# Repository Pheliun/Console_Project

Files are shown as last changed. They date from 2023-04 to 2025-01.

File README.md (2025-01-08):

This was my final project to get my Cyber Diploma.
It involved creating a basic functional console that when connected to a power supply (using micro usb b), will be able to utilize a microprocessor, with a display, micro sd card socket, and buttons.
For a detailed explanation regarding my project, here is my project book: https://docs.google.com/document/d/1XIzdJ6GN7S2lS_oo8KrGg07EBY5Gj0uBNZ1zpXOEC-Y/edit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

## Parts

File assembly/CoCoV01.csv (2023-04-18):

Comment | Designator | Footprint | LCSC
4.7uF | C1,C2,C4 | Capacitor_SMD:C_0805_2012Metric | C1779
10uF | C3,C5 | Capacitor_SMD:C_1206_3216Metric | C13585
100nF | C6,C7,C8 | Capacitor_SMD:C_0402_1005Metric | C24497
600mA | D1 | Diode_SMD:D_SOD-323 | C191023
MountingHole_Pad | H1,H2,H3,H4 | MountingHole:MountingHole_4.3mm_M4_Pad_Via
SWD CONN | J1 | Connector_PinHeader_1.27mm:PinHeader_2x05_P1.27mm_Vertical_SMD | C2881910
Conn_01x08_Female | J2,J5 | Connector_PinSocket_2.54mm:PinSocket_1x08_P2.54mm_Vertical
Micro_SD_Card | J3 | libraries:microSD_HC_Molex_104031-0811 | C585350
USB_B_Micro | J4 | Connector_USB:USB_Micro-B_Molex-105133-0001 | C782257
24k | R1,R2,R3,R4,R5,R6,R7,R8,R9 | Resistor_SMD:R_0805_2012Metric | C17575
B3F-1000 | S1,S2,S3,S4,S5,S6,S7,S8 | digikey-footprints:Switch_Tactile_THT_B3F-1xxx
LM1117MPX-3_3_NOPB | U1 | digikey-footprints:SOT-223
STM32F103TBUx | U2 | Package_DFN_QFN:QFN-36-1EP_6x6mm_P0.5mm_EP4.1x4.1mm | C1339380

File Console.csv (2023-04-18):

Comment | Designator | Footprint | LCSC
4.7uF | C1,C2,C4 | Capacitor_SMD:C_0805_2012Metric
10uF | C3,C5 | Capacitor_SMD:C_1206_3216Metric
100nF | C6,C7,C8 | Capacitor_SMD:C_0402_1005Metric
600mA | D1 | Diode_SMD:D_SOD-323
MountingHole_Pad | H1,H2,H3,H4 | MountingHole:MountingHole_4.3mm_M4_Pad_Via
SWD CONN | J1 | Connector_PinHeader_1.27mm:PinHeader_2x05_P1.27mm_Vertical_SMD
Conn_01x08_Female | J2,J5 | Connector_PinSocket_2.54mm:PinSocket_1x08_P2.54mm_Vertical
Micro_SD_Card | J3 | libraries:microSD_HC_Molex_104031-0811
USB_B_Micro | J4 | Connector_USB:USB_Micro-AB_Molex_47590-0001
24k | R1,R2,R3,R4,R5,R6,R7,R8,R9 | Resistor_SMD:R_0805_2012Metric
B3F-1000 | S1,S2,S3,S4,S5,S6,S7,S8 | digikey-footprints:Switch_Tactile_THT_B3F-1xxx
LM1117MPX-3_3_NOPB | U1 | digikey-footprints:SOT-223
STM32F103TBUx | U2 | Package_DFN_QFN:QFN-36-1EP_6x6mm_P0.5mm_EP4.1x4.1mm

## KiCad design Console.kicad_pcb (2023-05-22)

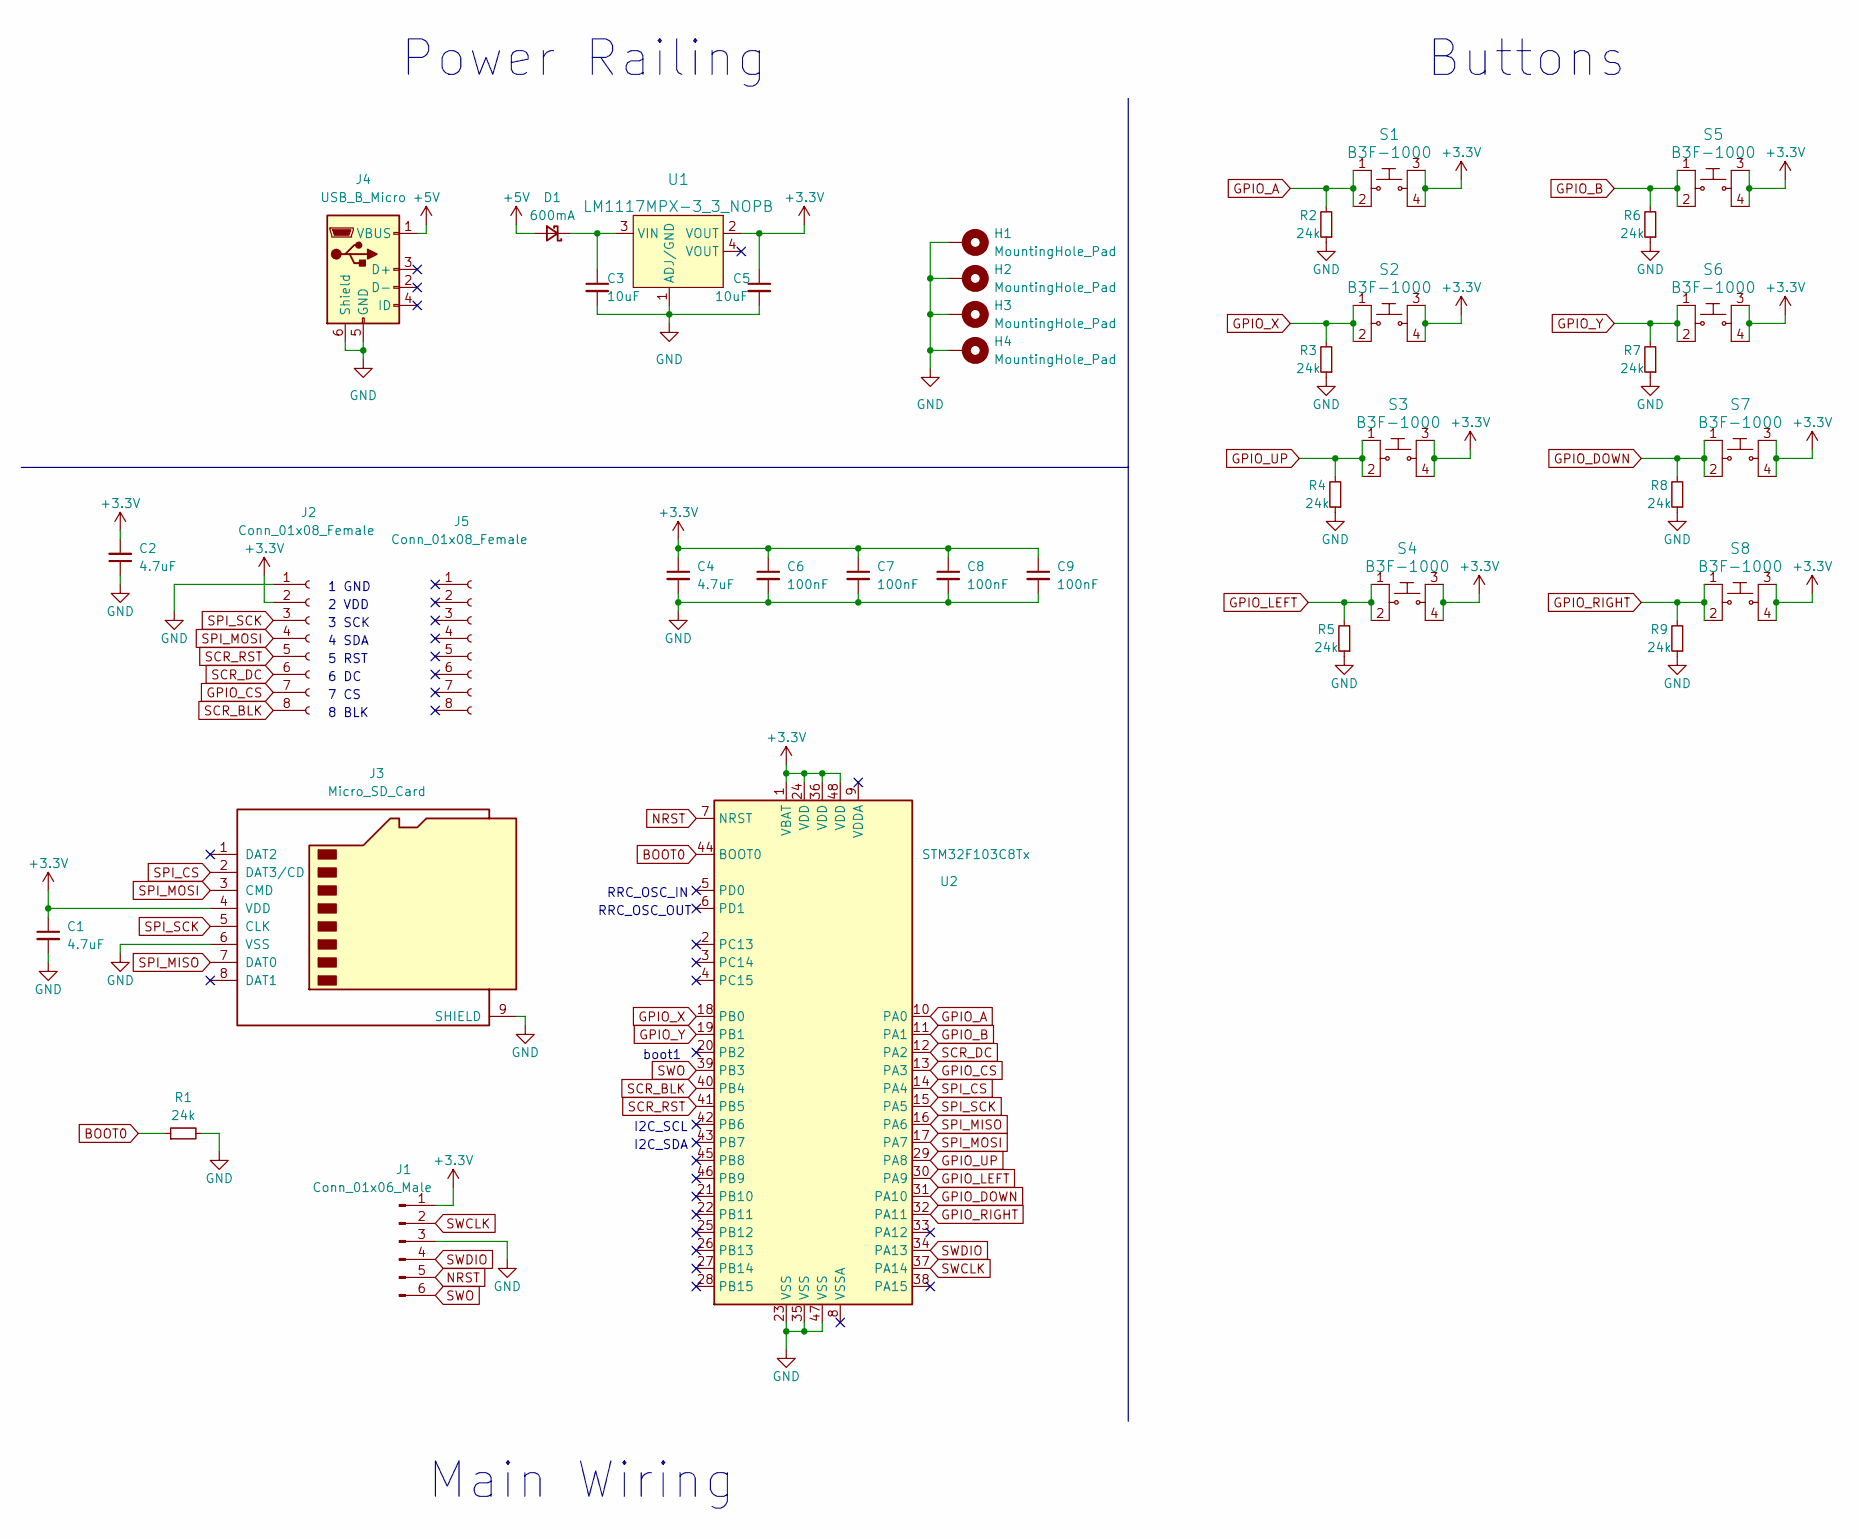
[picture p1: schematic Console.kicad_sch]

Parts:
C1, C2, C4: 4.7uF; C_0805_2012Metric; LCSC Part # C1779
C3, C5: 10uF; C_1206_3216Metric; LCSC Part # C13585
C6, C7, C8, C9: 100nF; C_0402_1005Metric; LCSC Part # C24497
D1: 600mA; D_SOD-323; LCSC Part # C191023
H1, H2, H3, H4: MountingHole_Pad; MountingHole_4.3mm_M4_Pad_Via
J1: Conn_01x06_Male; PinHeader_1x06_P2.54mm_Vertical
J2, J5: Conn_01x08_Female; PinSocket_1x08_P2.54mm_Vertical
J3: Micro_SD_Card; microSD_HC_Molex_104031-0811; LCSC Part # C585350
J4: USB_B_Micro; USB_Micro-B_Molex-105133-0001; LCSC Part # C782257
R1, R2, R3, R4, R5, R6, R7, R8, R9: 24k; R_0805_2012Metric; LCSC Part # C17575
S1, S2, S3, S4, S5, S6, S7, S8: B3F-1000; Switch_Tactile_THT_B3F-1xxx; MPN B3F-1000; Digi-Key_PN SW400-ND
U1: LM1117MPX-3_3_NOPB; SOT-223; MPN LM1117MPX-3.3/NOPB; Digi-Key_PN LM1117MPX-3.3/NOPBCT-ND
U2: STM32F103C8Tx; LQFP-48_7x7mm_P0.5mm

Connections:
+3.3V: C1.1, C2.2, C4.1, C5.1, C6.1, C7.1, C8.1, C9.1, J1.1, J2.2, J3.4 (VDD), S1.3, S1.4, S2.3, S2.4, S3.3, S3.4, S4.3, S4.4, S5.3, S5.4, S6.3, S6.4, S7.3, S7.4, S8.3, S8.4, U1.2 (VOUT), U2.1 (VBAT), U2.24 (VDD), U2.36 (VDD), U2.48 (VDD)
+5V: D1.2 (A), J4.1 (VBUS)
BOOT0: R1.1, U2.44 (BOOT0)
GND: C1.2, C2.1, C3.2, C4.2, C5.2, C6.2, C7.2, C8.2, C9.2, H1.1, H2.1, H3.1, H4.1, J1.3, J2.1, J3.6 (VSS), J3.9 (SHIELD), J4.5 (GND), J4.6 (Shield), R1.2, R2.1, R3.1, R4.1, R5.1, R6.1, R7.1, R8.1, R9.1, U1.1 (ADJ/GND), U2.23 (VSS), U2.35 (VSS), U2.47 (VSS)
GPIO_A: R2.2, S1.1, S1.2, U2.10 (PA0)
GPIO_B: R6.2, S5.1, S5.2, U2.11 (PA1)
GPIO_CS: J2.7, U2.13 (PA3)
GPIO_DOWN: R8.2, S7.1, S7.2, U2.31 (PA10)
GPIO_LEFT: R5.2, S4.1, S4.2, U2.30 (PA9)
GPIO_RIGHT: R9.2, S8.1, S8.2, U2.32 (PA11)
GPIO_UP: R4.2, S3.1, S3.2, U2.29 (PA8)
GPIO_X: R3.2, S2.1, S2.2, U2.18 (PB0)
GPIO_Y: R7.2, S6.1, S6.2, U2.19 (PB1)
NRST: J1.5, U2.7 (NRST)
unnamed: C3.1, D1.1 (K), U1.3 (VIN)
SCR_BLK: J2.8, U2.40 (PB4)
SCR_DC: J2.6, U2.12 (PA2)
SCR_RST: J2.5, U2.41 (PB5)
SPI_CS: J3.2 (DAT3/CD), U2.14 (PA4)
SPI_MISO: J3.7 (DAT0), U2.16 (PA6)
SPI_MOSI: J2.4, J3.3 (CMD), U2.17 (PA7)
SPI_SCK: J2.3, J3.5 (CLK), U2.15 (PA5)
SWCLK: J1.2, U2.37 (PA14)
SWDIO: J1.4, U2.34 (PA13)
SWO: J1.6, U2.39 (PB3)

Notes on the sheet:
5 RST
I2C_SCL
boot1
3 SCK
8 BLK
Main Wiring
Power Railing
4 SDA
I2C_SDA
1 GND
2 VDD
7 CS
RRC_OSC_OUT
RRC_OSC_IN
Buttons
6 DC

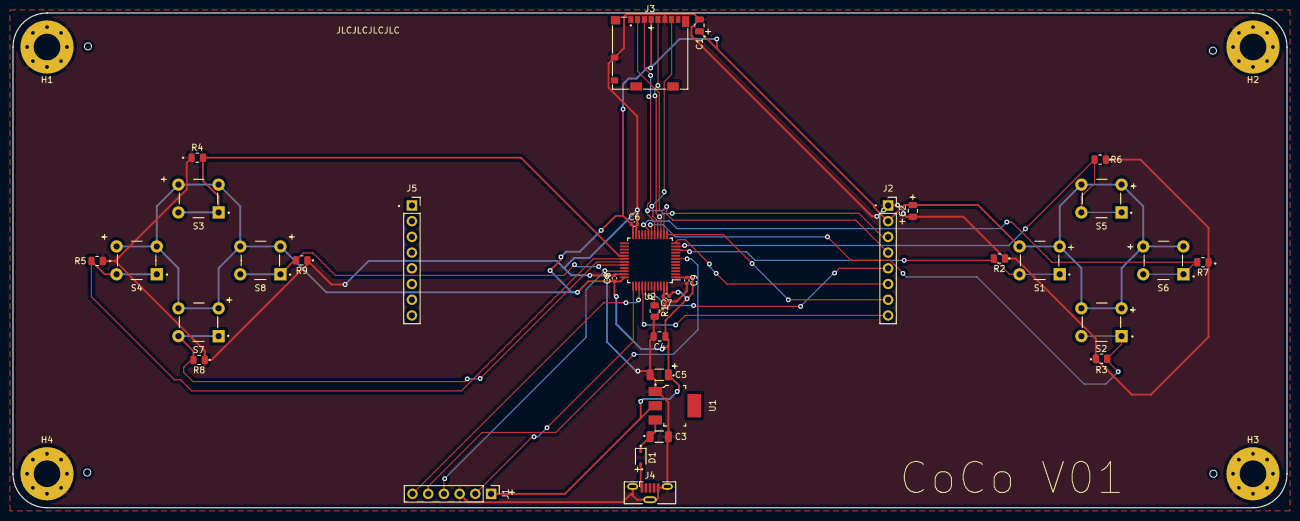
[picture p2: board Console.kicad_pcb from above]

Board: 2 copper layers, 206.0 x 80.0 mm, 38 parts (0 on the bottom side), 25 nets.

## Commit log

2023-03-18 small changes to schematics
    [Console.kicad_sch]
2023-03-26 added buttons to schema and changed routes a bit
    [Console.kicad_sch]
2023-04-15 changed the power railing, switched the boost converter with LDO
    [Console.kicad_sch]
2023-04-16 sorted power rails, assigned footprints etc
    [Console.kicad_sch]
2023-04-18 final commit (hopefully) for V01
    [CoCoV01.csv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]
2023-05-22 fixed problems, switched MCU with another of the same product line
    [Console.kicad_pcb, Console.kicad_sch]
